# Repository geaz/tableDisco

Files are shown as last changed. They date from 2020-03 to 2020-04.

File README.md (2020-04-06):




# TableDisco
**TableDisco** is a connected and music reactive table light. Each light is self operating and you can add as many lights as you want.

[TODO Video - Single Light, Connected Light (light mdoe, disco mode)]

The first powered **TableDisco** will start a naive *WiFi-Mesh* and is the *root* of the new **TableDisco** mesh. The *root disco* acts as the *sound analyzer* for the whole mesh. Each addtional powered **TableDisco** will automatically connect to the mesh.

On activation the **TableDiscos** are *"only"* pretty table lights. But as soon as
the *mode switcher* on the *root disco* is pressed, all **TableDiscos** will switch to the **Disco Mode**.

In **Disco Mode** the *root disco* will analyze the surrounding sound. By taking the volume and frequency into account, it will calculate a color and brightness. The *root disco* will then broadcast this color to the **TableDisco** mesh. Doing so, all **TableDiscos** will simultaneously react to the surrounding sound of the *root disco*.

Furthermore the **TableDisco** includes an OTA update mechanism (an additional *update server device* is necessary - *OTA Update* chapter for details).

## 3D Model
The model was designed in Fusion360. The STLs are included in the Thingiverse downloads and the Github repository. Furthermore there is an exported Fusion360 Archive File ready to download.

## BOM (for one TableDisco)

- 3D Printed Parts (STL folder for models)
- Wemos D1 Mini
- Resistor 100k
- Capacitor 680uF
- [Momentary Switch](https://ebay.us/w5SPS8)
- [SPST Switch](https://www.amazon.de/dp/B076GXD7XN)
- MAX4466
- TP4056 charging board (make sure you buy one rated for 1A and with integrated load protection)
- [Battery Case](https://www.amazon.de/dp/B077XW1F9C) 
- [Li-Ion 18650 (I used a 3350mAh one)](https://ebay.us/9vmIsS)
- [4x WS2812B LEDs (I used a strip and cut it)](https://www.amazon.de/dp/B01CDTED80)
- 4x M2x12mm screws
- [Stripboard](https://www.amazon.com/dp/B00C9NXP94)
- Wire
- Double-faced adhesive tape

## Firmware

Before building the **TableDisco** you should flash the firmware onto the Wemos D1 Mini. This way you are able to make sure that it is functional.

Open the *src/firmware* folder in [Visual Studio Code](https://code.visualstudio.com/). This project uses [PlatformIO](https://platformio.org/platformio-ide) to develop the firmware. Install the PlatformIO extension into Visual Studio Code.

To flash the firmware onto the Wemos connect it to your PC and press the *Upload* button in the status bar.

TableDisco - Flash

Aftererwards start the *Serial Monitor* and you should see some outputs like in the screenshot below. If you are able to see the output, the device is working and you are ready to build the **TableDisco**.

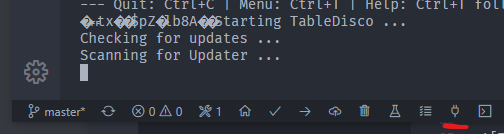
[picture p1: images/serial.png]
TableDisco - Serial


## Build

For the first step take the printed *Base* and *Battery Indicator*. The *Battery Indicator* has to be inserted, hollow side to the bottom, into the little hole at the side of the *Base*. Use a pliers and a bit of force. It is a pretty tight fit.

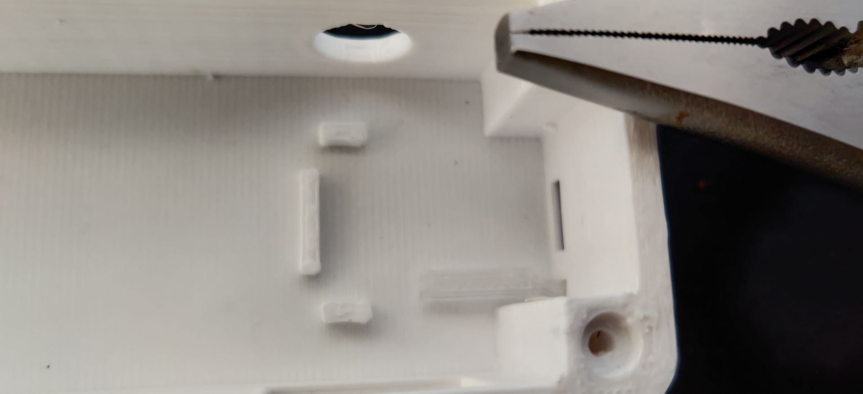
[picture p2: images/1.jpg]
TableDisco - 1


Prepare eleven ~5cm long wires and three ~10cm wires. This will be enough for the whole build. Take the three long wires and solder them onto the led strip.

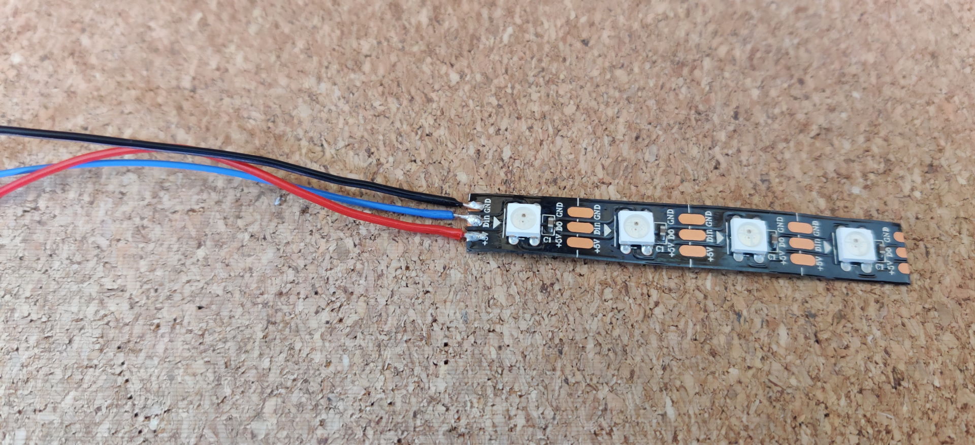
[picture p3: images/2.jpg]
TableDisco - 2


A piece of the stripboard (5x7 holes - in the picture below it is 5x9 for display pusposes - a 5x7 hole piece is sufficient for the build), the resistor and the capacitor are needed for the next step. Please use the next two pictures as a reference how to solder the stripboard. I recommend to solder the resistor first, then the wires and as a last step the capacitor (keep the polarity of the capacitor in mind).

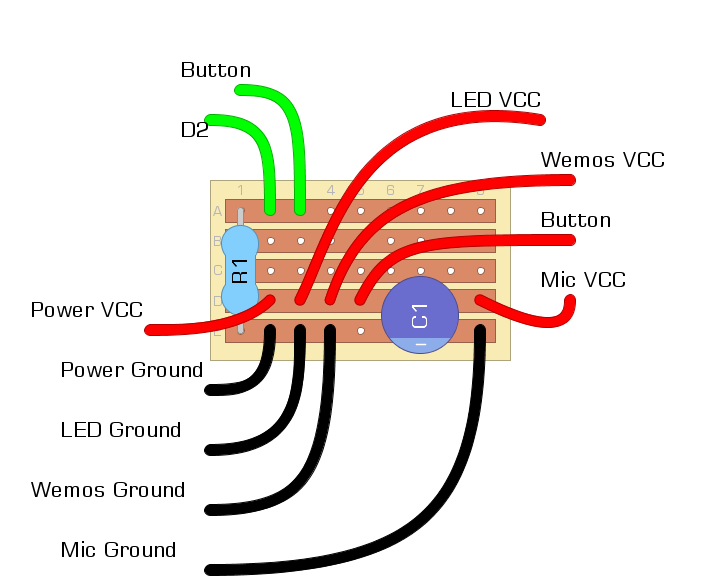
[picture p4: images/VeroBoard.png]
TableDisco - VeroBoard


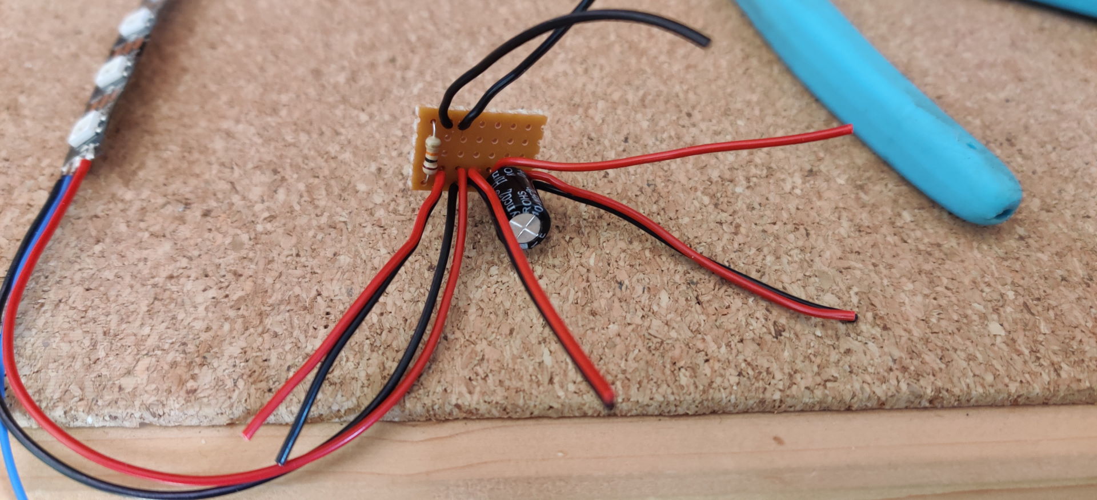
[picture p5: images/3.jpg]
TableDisco - 3


Now solder the battery case onto the battery pins of the TP4056. Solder the wire labeled *Power Ground*, in the strip board picture above, to the *OUT-* pin and a single ~5cm wire to te *OUT+* pin.

Take a pliers and grab the *battery indicator* and lift it up. Carefully slide the charging board into its position. **The LEDs are very easy to break. Be careful!** Use double-faced adhesive tape to mount the battery case into the *Base*.

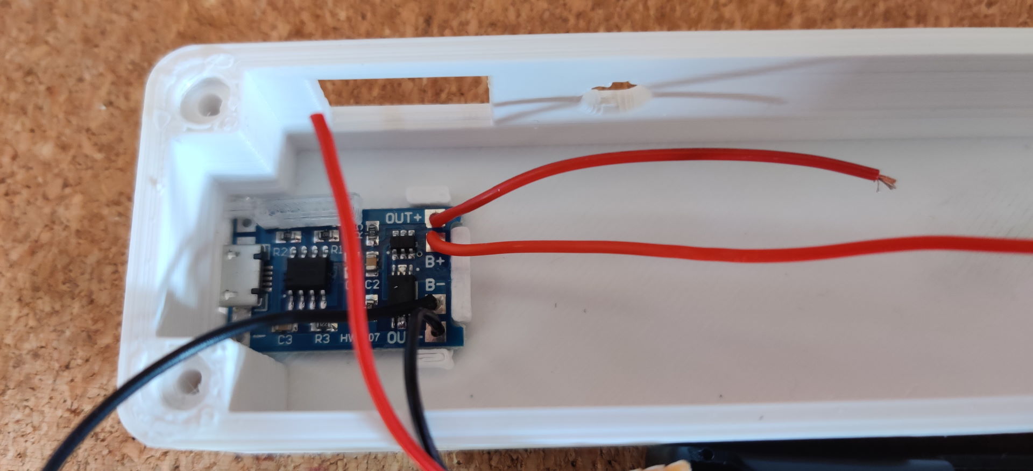
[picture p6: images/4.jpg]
TableDisco - 4


Insert the SPST switch into the case and solder the single wire of the *OUT+* pin to one end and the *Power VCC* of the stripboard to the other end.

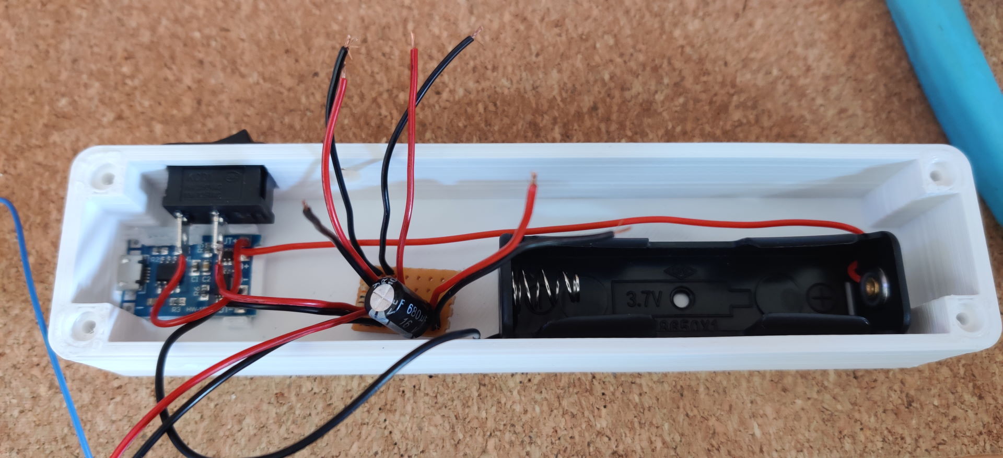
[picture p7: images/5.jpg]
TableDisco - 5


Now solder the two *Button* wires of the stripboard to the momentary switch and insert it into the case.
Solder the last ~5cm wire to the *OUT* pin of the microphone (MAX4466) and additionaly the two *Mic* wires of the stripboard to the *VCC* and *GND*. Insert the MAX4466 into the last whole of the *Base*.

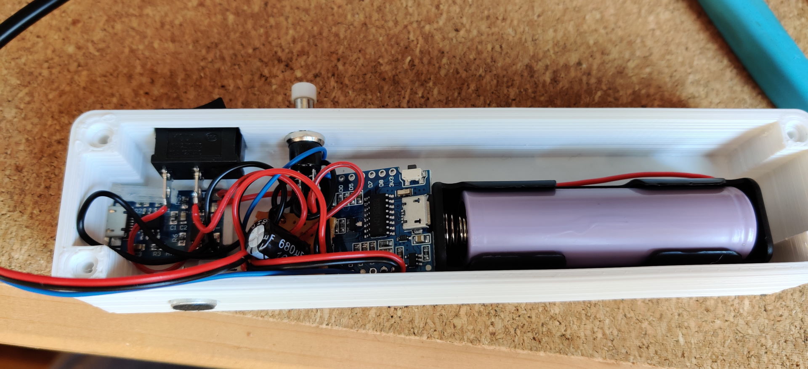
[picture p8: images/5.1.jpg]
TableDisco - 5.1


Take the *Middle*, the *Transparent* part and the *Top*. First use the *Middle* and tape the LEDs on it.

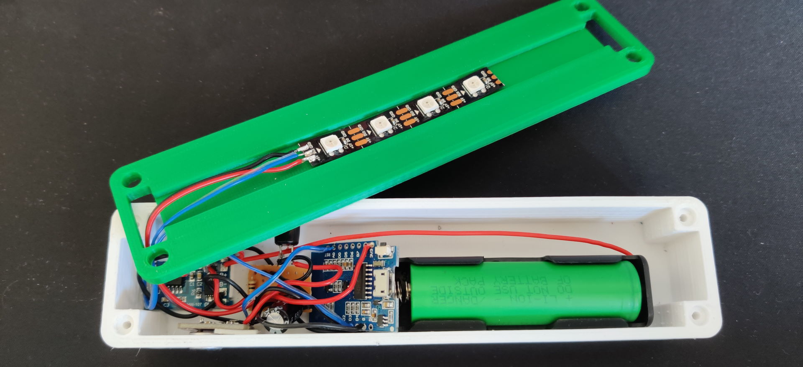
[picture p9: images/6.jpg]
TableDisco - 6


Place the *Transparent* and finally the *Top* on it. Insert the *Bolts* and use the screws to lock the **TableDisco**.

Your **TableDisco** is done!

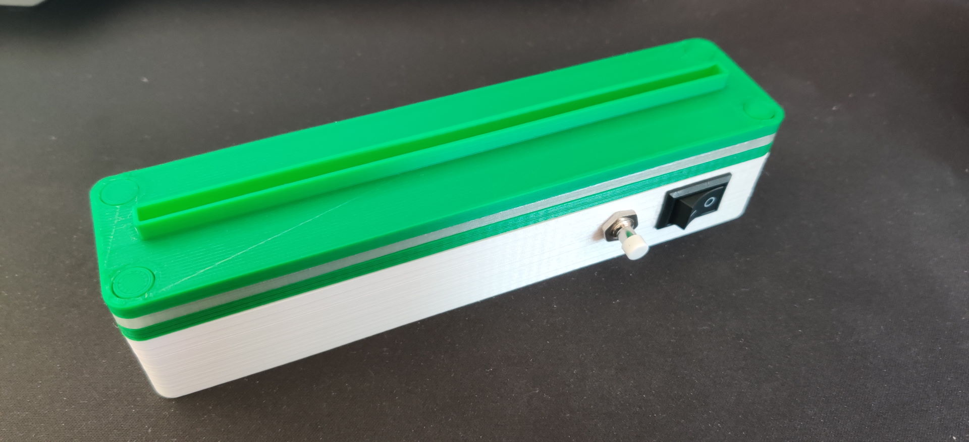
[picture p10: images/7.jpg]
TableDisco - 7


## OTA Update

The **TableDisco** firmware provides the functionality for OTA (over the air) updates. To update the firmware on all **TableDiscos** you have to flash a spare *Wemos D1 Mini* device with the *updater firmware*.

Open the *src/updater* folder in Visual Studio Code and connect the spare device to your PC. Flash the *updater firmware* (same procedure as uploading the firmware for the **TableDisco**) and copy the **TableDisco** *firmware.bin update* file to the *src/updater/data* folder.

Press the *Upload File System image* task button in Visual Studio Code. This will copy the new firmware to the update device.

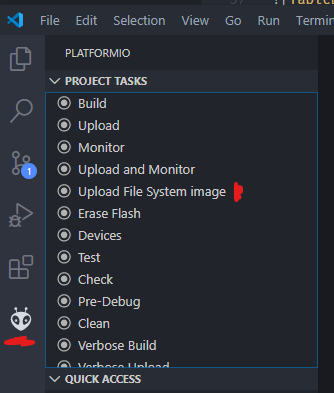
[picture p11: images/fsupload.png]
TableDisco - FSTask


To update the **TableDiscos** switch on your *update device* (connect it to USB for example). This will create a WiFi Access Point to which the **TableDiscos** are able to connect.

On the **TableDiscos** hold the *mode switcher* button and switch it on. The light of the **TableDisco** will be *Cyan*. This indicates, that the **TableDisco** is in update mode and is scanning for the *update device*. The light will switch to *Yellow*, if the updater was found and that the **TableDisco** is connecting to it. The *Blue* light indicates, that the device is connected to the updater and is downloading and installing the new firmware. **Do not switch off the devices during this step!**

Afterwards the **TableDisco** will automatically restart with the new firmware installed.

TableDisco - OTA (https://youtu.be/ygwx93fGblA)  
> Click picture to play video of the process on YouTube.

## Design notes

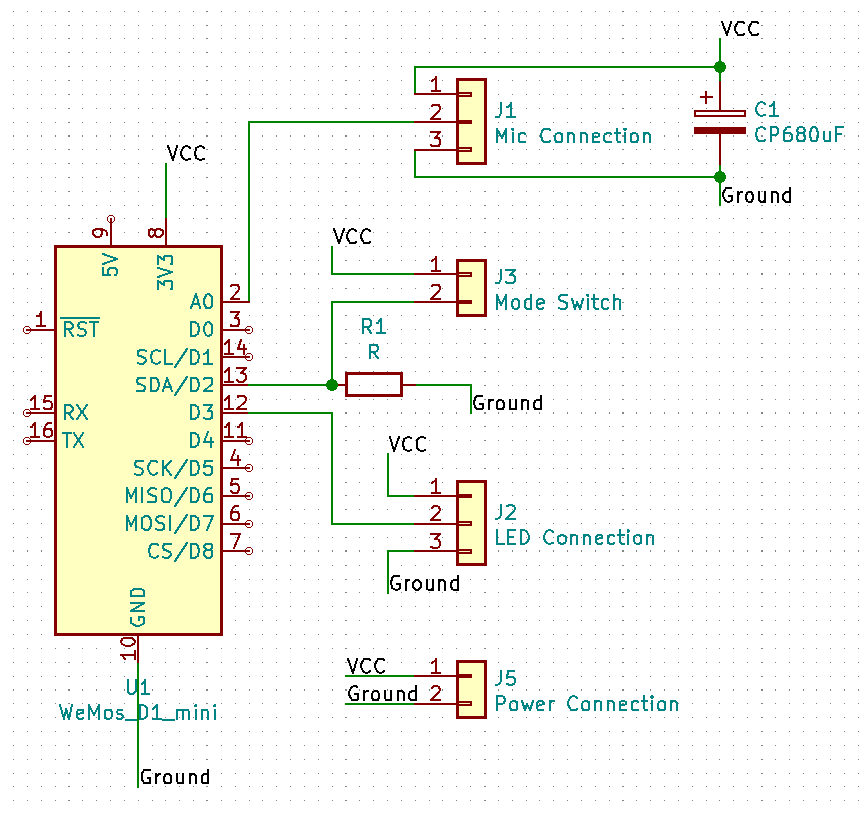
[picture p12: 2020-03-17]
images/Schematics.png

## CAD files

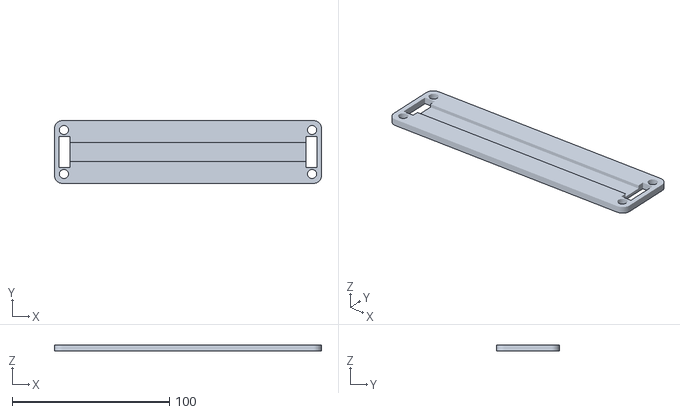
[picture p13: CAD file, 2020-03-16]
stl/Middle.stl
170.0 x 40.0 x 4.00

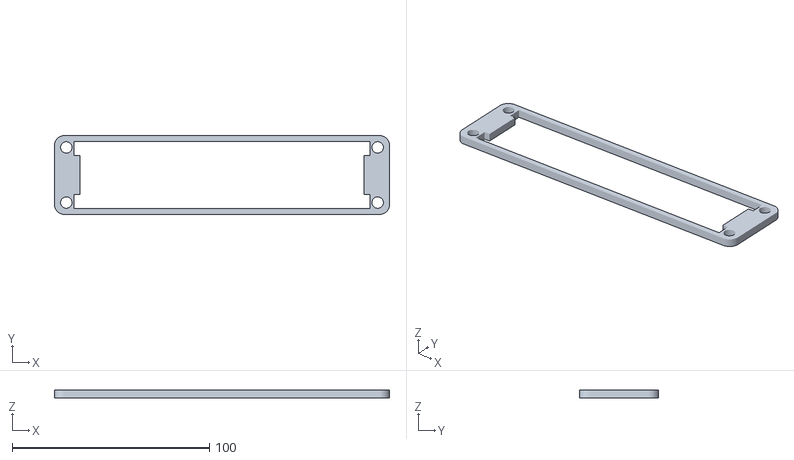
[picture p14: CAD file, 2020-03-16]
stl/Transparent.stl
170.0 x 40.0 x 4.00

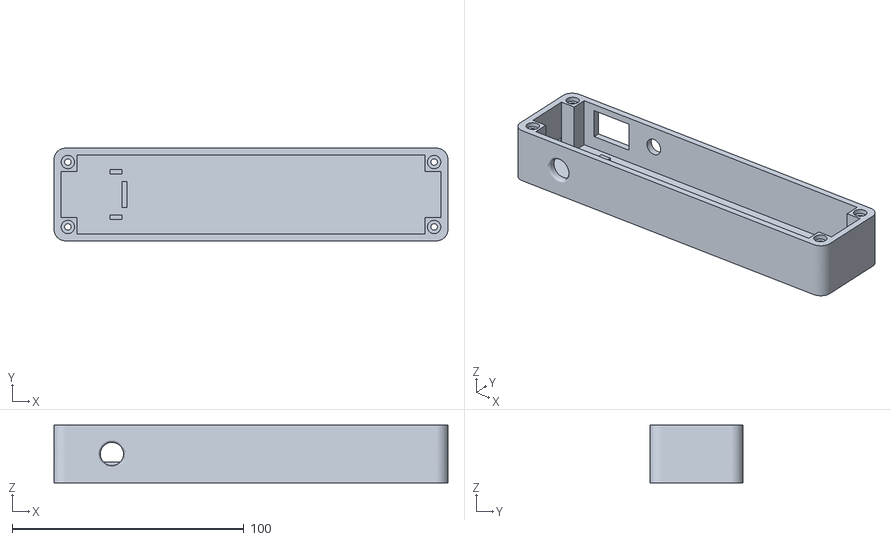
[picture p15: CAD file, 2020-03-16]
stl/Base.stl
170.0 x 40.0 x 25.0

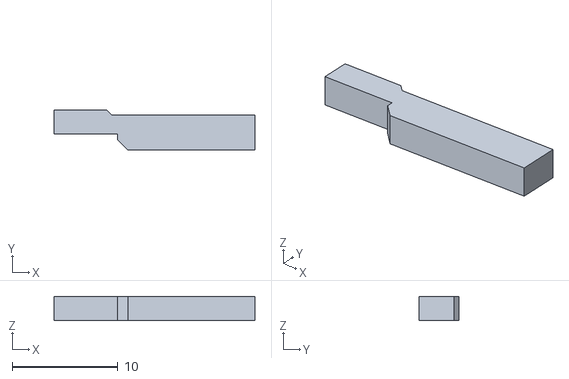
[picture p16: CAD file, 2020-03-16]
stl/Battery Indicator.stl
19.0 x 3.80 x 2.30

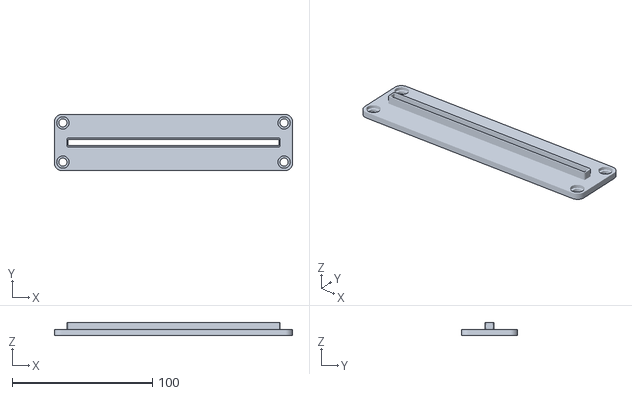
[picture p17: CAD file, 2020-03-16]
stl/Top.stl
170.0 x 40.0 x 9.00

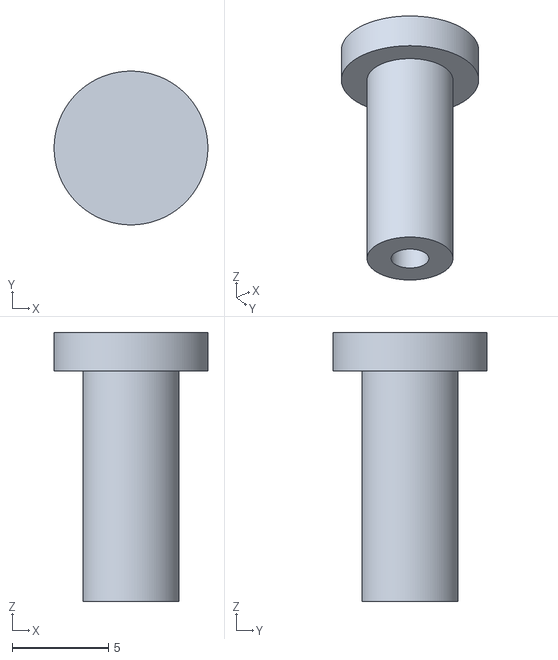
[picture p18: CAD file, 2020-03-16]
stl/Bolzen.stl
8.00 x 8.00 x 14.0

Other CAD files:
cad/TableDisco.f3z

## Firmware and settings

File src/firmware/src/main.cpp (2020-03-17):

#include <Arduino.h>
#include <ESP8266WiFi.h>
#include <ESP8266httpUpdate.h>
#include "led/led.hpp"
#include "wifi/disco_wifi.hpp"
#include "disco/disco.hpp"

TableDisco::LED led;
TableDisco::DiscoWifi wifi;
TableDisco::Disco disco(led, wifi);
char lastButtonVal = LOW;
unsigned long lastButtonUpdate = 0;

void checkModeButton();

void setup() 
{
    Serial.begin(9600);    
    Serial.println("Starting TableDisco ...");
    pinMode(A0, INPUT);     // Mic Input
    pinMode(D2, INPUT);     // Switch Mode Button
    pinMode(D3, OUTPUT);    // LED Data

    // Check for updater, if button pressed during startup
    if(digitalRead(D2) == HIGH)
    {
        led.setColor(TableDisco::Cyan);
        Serial.println("Checking for updates ...");
        Serial.println("Scanning for Updater ...");

        while(!wifi.isUpdaterAvailable())
        {
            delay(500);
            Serial.print(".");
            led.blink(TableDisco::Cyan, 1);
        }
        Serial.println();

        led.setColor(TableDisco::Yellow);
        wifi.connectToUpdater();
        led.setColor(TableDisco::Blue);
        ESPhttpUpdate.update("192.168.255.1", 80, "/update");        
    }
    // Else start normally
    else
    {
        // Setting up Disco
        wifi.startMesh();
        disco.setup();
    }
}

void loop() 
{    
    checkModeButton();
    disco.loop();
}

// Check, if the switch mode button was pressed
void checkModeButton()
{
    // Only check the button every 100 millis
    // this was necessary because of the button type I was using in my build
    if(lastButtonUpdate + 100 > millis()) return;

    char buttonVal = digitalRead(D2);
    if(buttonVal == HIGH && lastButtonVal == LOW)
    {
        disco.switchMode();
    }
    lastButtonVal = buttonVal;
    lastButtonUpdate = millis();
}

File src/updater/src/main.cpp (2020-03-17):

#include <ESP8266WiFi.h>
#include <ESPAsyncTCP.h>
#include <ESPAsyncWebServer.h>
#include <FS.h>

AsyncWebServer server(80);

void setup()
{
    Serial.begin(9600);
    Serial.println("Starting Update Device ...");
    if(!SPIFFS.begin()){
        Serial.println("An Error has occurred while mounting SPIFFS");
        return;
    }

    Serial.println("Starting Access Point ...");
    WiFi.disconnect();
    WiFi.mode(WIFI_AP);
    WiFi.softAPConfig(
        IPAddress(192, 168, 255, 1), 
        IPAddress(0, 0, 0, 0), 
        IPAddress(255, 255, 255, 0));
    WiFi.softAP("Table Disco Updater", "FunkyUpdates", 1, false, 8);

    Serial.println("Setting up web server ...");
    server.on("/", HTTP_GET, [](AsyncWebServerRequest *request){
        request->send(SPIFFS, "/index.html", String(), false);
    });
    server.on("/update", HTTP_GET, [](AsyncWebServerRequest *request){
        request->send(SPIFFS, "/firmware.bin", "application/octet-stream", true);
    });
    server.begin();

    Serial.println("Device ready!");
}

void loop() { }

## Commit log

2019-11-15 Refactoring and fixing LED interface
    [main.cpp, mesh.cpp, visualization.cpp]
2019-11-15 LED glitch fix
2019-11-17 Handle all cases in socket event
2020-03-08 Add Schematics
    [tableDisco.sch]
2020-03-09 Fix button press and Broadcast Bug
    [main.cpp]
2020-03-16 Add STLs
    [Base.stl, Battery Indicator.stl, Bolzen.stl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]
2020-03-16 Fix a few bugs
    [main.cpp]
2020-03-17 Add CAD and begin Readme
    [TableDisco.f3z]
2020-03-17 Add schematic image
2020-03-17 Fix capacitor value
    [tableDisco.sch]
